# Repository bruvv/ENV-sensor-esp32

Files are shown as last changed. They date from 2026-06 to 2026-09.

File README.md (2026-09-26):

# ENV Sensor ESP32

Custom ESP32-S3 environmental sensor PCB designed for use with ESPHome and Home Assistant.

The board combines several environmental sensors, a 128×128 OLED display and an HLK-LD2450 mmWave presence sensor on a compact custom PCB.

## Features

- ESP32-S3 DevKitC N16R8
- Sensirion SCD30 CO₂ sensor
- Sensirion SEN55 environmental sensor
- MS5611 barometric pressure sensor
- BH1750 ambient light sensor
- ZJY-M150 128×128 OLED with SSD1327 controller
- HLK-LD2450 mmWave presence sensor
- Shared I²C bus for environmental sensors
- SPI interface for the OLED display
- Hardware UART for the LD2450
- 5 V and 3.3 V power rails
- 4-layer PCB
- 55 × 70 mm board
- Designed in KiCad 10

## Sensors

| Component | Function | Supply | Interface |
| --- | --- | ---: | --- |
| ESP32-S3 DevKitC N16R8 | Main controller, Wi-Fi and Bluetooth | 5 V | - |
| Sensirion SCD30 | CO₂, temperature and humidity | 5 V | I²C |
| Sensirion SEN55 | PM1.0, PM2.5, PM4, PM10, VOC, NOx, temperature and humidity | 5 V | I²C |
| MS5611 | Barometric pressure | 3.3 V | I²C |
| BH1750 | Ambient light | 3.3 V | I²C |
| ZJY-M150 / SSD1327 | 128×128 OLED display | 3.3 V | SPI |
| HLK-LD2450 | mmWave presence and multi-target tracking | 5 V | UART |

## ESP32 Pin Mapping

### I²C

| Signal | ESP32-S3 |
| --- | --- |
| SDA | GPIO8 |
| SCL | GPIO9 |

The environmental sensors share the I²C bus.

| Sensor | I²C address |
| --- | ---: |
| SCD30 | `0x61` |
| SEN55 | `0x69` |
| BH1750 | `0x23` |
| MS5611 | `0x77` |

The PCB contains 4.7 kΩ pull-up resistors for SDA and SCL.

## SSD1327 OLED

The ZJY-M150 OLED is operated in 4-wire SPI mode.

| OLED signal | ESP32-S3 |
| --- | --- |
| CS | GPIO10 |
| MOSI / SDA | GPIO11 |
| CLK / SCL | GPIO12 |
| DC | GPIO13 |
| RESET | GPIO14 |

## HLK-LD2450

The LD2450 uses a dedicated hardware UART.

| Signal | ESP32-S3 |
| --- | --- |
| LD2450 RX | GPIO17 / ESP32 TX |
| LD2450 TX | GPIO18 / ESP32 RX |

UART configuration:

- Baud rate: `256000`
- Data bits: `8`
- Parity: none
- Stop bits: `1`

## PCB

The current PCB revision is designed in KiCad 10.

| Property | Value |
| --- | --- |
| Dimensions | 55 × 70 mm |
| Copper layers | 4 |
| Top copper | `F.Cu` |
| Inner layer 1 | `In1.Cu` |
| Inner layer 2 | `In2.Cu` |
| Bottom copper | `B.Cu` |

The repository contains the KiCad project files as well as production Gerber and drill files.

## LD2450 Connector

The HLK-LD2450 is connected through an 8-pin dual-row SMD female socket.

Required connector specification:

| Property | Requirement |
| --- | --- |
| Type | Female PCB socket |
| Contacts | 8 |
| Rows | 2 × 4 |
| Pitch | 2.00 mm |
| Mounting | SMD / SMT |
| Orientation | Straight |

A suitable branded connector is:

**Würth Elektronik 62100821821**

- 2 × 4
- 8 contacts
- 2.00 mm pitch
- Female
- SMD

For generic alternatives, search for:

`2.0mm 2x4 8 pin female SMD header`

## SEN55 Connection

The SEN55 is mounted away from the main PCB to keep its airflow unobstructed.

The connection provides:

| Signal |
| --- |
| 5 V |
| GND |
| SDA |
| SCL |
| GND / SEL |

## Bill of Materials

| Qty | Component | Notes |
| ---: | --- | --- |
| 1 | ESP32-S3 DevKitC N16R8 | ESP32-S3-WROOM based |
| 1 | Sensirion SCD30 | CO₂ sensor |
| 1 | Sensirion SEN55 | Environmental and particulate sensor |
| 1 | MS5611 module | Pressure sensor |
| 1 | BH1750 module | Ambient light sensor |
| 1 | ZJY-M150 128×128 OLED | SSD1327 controller, 7-pin |
| 1 | HLK-LD2450 | mmWave presence sensor |
| 1 | 2×4 2.00 mm female SMD socket | LD2450 connector |
| 2 | 4.7 kΩ resistor | I²C pull-ups |

## Design Considerations

### SCD30

The SCD30 should be kept away from heat sources and strong direct airflow that could influence its temperature and CO₂ measurements.

Datasheet:  
https://sensirion.com/media/documents/4EAF6AF8/61652C3C/Sensirion_CO2_Sensors_SCD30_Datasheet.pdf

### SEN55

The SEN55 requires unobstructed airflow through its inlet and outlet.

For best performance:

- Keep the inlet and outlet separated.
- Avoid recirculating exhaust air into the inlet.
- Keep the sensor away from heat sources.
- Orient the sensor so dust cannot easily accumulate inside.
- Keep the fan inlet and exhaust unobstructed.

Datasheet:  
https://sensirion.com/media/documents/6791EFA0/62A1F68F/Sensirion_Datasheet_Environmental_Node_SEN5x.pdf

### MS5611

Keep the pressure sensor away from the ESP32 voltage regulator and other heat-producing components.

Datasheet:  
https://www.te.com/commerce/DocumentDelivery/DDEController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

### BH1750

The BH1750 needs a clear optical path to the room.

Avoid placing it behind opaque enclosure material or in the shadow of other components.

Datasheet:  
https://components101.com/sites/default/files/component_datasheet/BH1750.pdf

### SSD1327 OLED

The display is a ZJY-M150 1.5-inch 128×128 OLED using an SSD1327 controller.

The PCB uses SPI for the display.

SSD1327 datasheet:  
https://www.waveshare.com/w/upload/a/ac/SSD1327-datasheet.pdf

### HLK-LD2450

The LD2450 provides mmWave presence detection and multi-target position tracking.

Placement and enclosure design can significantly affect radar performance.

Recommendations:

- Face the radar toward the room.
- Avoid metal directly in front of the antenna.
- Keep sufficient clearance around the antenna area.
- Avoid placing large copper areas or metal parts directly in the radar field of view.

## Repository Structure

`envsensor/`  
KiCad schematic, PCB project and project-specific libraries.

`gerber/`  
Production Gerber and drill files.

`datasheet/`  
Component documentation.

`docs/`  
Hardware design and implementation documentation.

`README.md`  
Project documentation.

## Manufacturing

The `gerber/` directory contains the generated PCB production files, including:

- `F.Cu`
- `In1.Cu`
- `In2.Cu`
- `B.Cu`
- `F.Mask`
- `B.Mask`
- `F.Paste`
- `B.Paste`
- `F.Silkscreen`
- `B.Silkscreen`
- `Edge.Cuts`
- PTH drill file
- NPTH drill file

The repository also contains `gerber/gerber.zip`, which can be uploaded to most PCB manufacturers.

Always verify the Gerbers in the PCB manufacturer's Gerber viewer before placing an order.

## Software

The board is intended for use with ESPHome and Home Assistant.

Useful ESPHome documentation:

- SCD30: https://esphome.io/components/sensor/scd30/
- SEN5x: https://esphome.io/components/sensor/sen5x/
- BH1750: https://esphome.io/components/sensor/bh1750/
- MS5611: https://esphome.io/components/sensor/ms5611/
- SSD1327: https://esphome.io/components/display/ssd1327/
- LD2450: https://esphome.io/components/sensor/ld2450/

## License

See [LICENSE](LICENSE).

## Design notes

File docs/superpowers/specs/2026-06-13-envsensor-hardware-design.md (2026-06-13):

# ENV Sensor Hardware Design

## Scope

Finish and clean the KiCad schematic and PCB in `envsensor/`.

The board uses complete modules:

- ESP32-S3 DevKit from the existing project footprint
- Sensirion SCD30
- Sensirion SEN55, connected by cable
- MS5611 breakout
- Waveshare 1.5-inch SSD1327 128x128 OLED module
- BH1750 breakout
- HLK-LD2450 using the existing project footprint and onboard header

The PCB remains 52 x 70 mm. It has no mounting holes.

## Interfaces

### I2C

Use one shared 3.3 V I2C bus:

- SDA: ESP32-S3 GPIO8
- SCL: ESP32-S3 GPIO9
- SCD30: address 0x61
- SEN55: address 0x69
- BH1750: address 0x23
- MS5611: address 0x77

Add one pair of 4.7 kOhm pull-up resistors to 3.3 V. Keep the bus suitable
for the external SEN55 cable. Connect SEN55 SEL to GND to select I2C.

### Display

Use the SSD1327 in its factory-default four-wire SPI mode:

- MOSI: GPIO11
- CLK: GPIO12
- CS: GPIO10
- DC: GPIO13
- RESET: GPIO14

The display is powered from 3.3 V.

### Radar

Use a hardware UART for the LD2450:

- ESP32 TX: GPIO17 to LD2450 RX
- ESP32 RX: GPIO18 from LD2450 TX
- 256000 baud, no parity, one stop bit

Preserve the existing LD2450 footprint as the mechanical basis.

## Power

Power the assembly through the ESP32-S3 DevKit USB connector.

- 5VIN powers SCD30, SEN55, and LD2450.
- 3V3 powers SSD1327, BH1750, MS5611, and I2C pull-ups.
- Add local bulk and decoupling capacitance on both rails.
- Use wider 5 V tracks for the fan-based SEN55 and other 5 V modules.

Do not use ESP32-S3 strapping pins, native USB pins, or flash/PSRAM pins
for these interfaces.

## Connectors And Assembly

- SCD30, MS5611, BH1750, SSD1327, and ESP32-S3 are soldered to the board.
- SEN55 sits away from the PCB and connects through a JST GHR-06V-S
  six-pin cable connector.
- LD2450 plugs directly into the existing onboard header arrangement.
- Place clear silkscreen labels for module names, connector pinout, pin 1,
  power rails, and orientation.

## Mechanical Layout

Use layout option A.

Front:

- SSD1327 at the top.
- BH1750 below the display with an unobstructed light path.
- LD2450 at the bottom, facing into the room.

Back:

- ESP32-S3 on the left, with USB accessible at the bottom edge.
- SCD30 on the right with unobstructed airflow openings.
- MS5611 below the SCD30 and away from heat sources.
- SEN55 connector at the bottom edge.

Keep SCD30 and MS5611 away from the ESP32 regulator and other heat sources.
Respect antenna and copper keep-out requirements for the ESP32-S3 and
LD2450.

## Schematic Structure

Organize the schematic into readable blocks:

1. Power and decoupling
2. ESP32-S3
3. I2C sensors
4. SSD1327 display
5. LD2450 radar

Use these references:

- U1: ESP32-S3
- U2: SCD30
- U3: MS5611
- U4: BH1750
- U5: SSD1327
- J1: SEN55
- U6: LD2450

Mark intentionally unused module pins as no-connect.

## PCB Routing

- Use two copper layers with GND pours.
- Keep I2C tracks short, grouped, and away from noisy power routing.
- Keep SPI routing short between ESP32-S3 and SSD1327.
- Route UART separately from sensor lines.
- Provide clean return paths and stitching vias where useful.
- Preserve the 52 x 70 mm rectangular board outline.

## Validation

- Run KiCad ERC on the finished schematic.
- Run KiCad DRC on the fully placed and routed PCB.
- Resolve all actionable findings.
- Document any accepted warning with a concrete hardware reason.
- Confirm footprints, connector orientation, module clearances, power
  rails, and pin mappings against manufacturer documentation.

ESPHome configuration is outside this task.

## Sources

- ESPHome SSD1327:
  https://esphome.io/components/display/ssd1327/
- ESPHome I2C:
  https://esphome.io/components/i2c/
- ESPHome SCD30:
  https://esphome.io/components/sensor/scd30/
- ESPHome SEN5x:
  https://esphome.io/components/sensor/sen5x/
- ESPHome BH1750:
  https://esphome.io/components/sensor/bh1750/
- ESPHome MS5611:
  https://esphome.io/components/sensor/ms5611/
- ESPHome LD2450:
  https://esphome.io/components/sensor/ld2450/
- Waveshare SSD1327 module:
  https://www.waveshare.com/wiki/1.5inch_OLED_Module
- Sensirion SEN5x datasheet:
  https://sensirion.com/media/documents/6791EFA0/62A1F68F/Sensirion_Datasheet_Environmental_Node_SEN5x.pdf
- Espressif ESP32-S3 GPIO restrictions:
  https://docs.espressif.com/projects/esp-idf/en/stable/esp32s3/api-reference/peripherals/gpio.html

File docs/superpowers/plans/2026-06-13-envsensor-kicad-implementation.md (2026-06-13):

# ENV Sensor KiCad Implementation Plan

> **For agentic workers:** REQUIRED SUB-SKILL: Use superpowers:subagent-driven-development (recommended) or superpowers:executing-plans to implement this plan task-by-task. Steps use checkbox (`- [ ]`) syntax for tracking.

**Goal:** Deliver a clean KiCad 10 schematic and fully placed, routed, two-layer 52 x 70 mm PCB for the ESPHome environmental sensor.

**Architecture:** Restore the useful KiCad recovery files into the active project, then rebuild connectivity around one 3.3 V I2C bus, one SSD1327 SPI bus, and one LD2450 hardware UART. Reuse the existing module footprints where they match the hardware, add only the missing display and SEN55 connector definitions, and validate the result with KiCad ERC, DRC, schematic parity, and visual exports.

**Tech Stack:** KiCad 10.0.3, `kicad-cli`, KiCad schematic editor, KiCad PCB editor, two-layer PCB.

---

## File Map

- Modify: `envsensor/envsensor.kicad_sch` - complete schematic and net definitions.
- Create: `envsensor/envsensor.kicad_pcb` - active routed PCB restored from the best recovery board.
- Modify: `envsensor/envsensor.kicad_pro` - project rules and library references where required.
- Modify: `envsensor/sym-lib-table` - project-local symbol library registration.
- Modify: `envsensor/fp-lib-table` - project-local footprint library registration.
- Create: `envsensor/lib/envsensor.kicad_sym` - missing module symbols only.
- Create: `envsensor/lib/envsensor.pretty/SSD1327_Waveshare_1.5in.kicad_mod` - display module footprint and mechanical outline.
- Create: `envsensor/reports/erc.json` - final ERC report.
- Create: `envsensor/reports/drc.json` - final DRC and schematic parity report.
- Create: `envsensor/reports/front.png` - top-side 3D visual review export.
- Create: `envsensor/reports/back.png` - bottom-side 3D visual review export.

## Fixed Net Map

| Net | ESP32-S3 pin | Destinations |
| --- | --- | --- |
| `I2C_SDA` | GPIO8 | SCD30 SDA, SEN55 SDA, MS5611 SDA, BH1750 SDA |
| `I2C_SCL` | GPIO9 | SCD30 SCL, SEN55 SCL, MS5611 SCL, BH1750 SCL |
| `OLED_CS` | GPIO10 | SSD1327 CS |
| `OLED_MOSI` | GPIO11 | SSD1327 DIN |
| `OLED_CLK` | GPIO12 | SSD1327 CLK |
| `OLED_DC` | GPIO13 | SSD1327 DC |
| `OLED_RST` | GPIO14 | SSD1327 RST |
| `RADAR_TX` | GPIO17 | LD2450 RX |
| `RADAR_RX` | GPIO18 | LD2450 TX |
| `+5V` | 5VIN | SCD30 VDD, SEN55 VDD, LD2450 5V |
| `+3V3` | 3V3 | SSD1327 VCC, MS5611 VCC, BH1750 VCC, I2C pull-ups |
| `GND` | GND | All modules and decoupling |

### Task 1: Restore Active KiCad Board

**Files:**
- Replace: `envsensor/envsensor.kicad_sch`
- Create: `envsensor/envsensor.kicad_pcb`

- [ ] **Step 1: Preserve the active schematic outside the implementation diff**

Copy `envsensor/envsensor.kicad_sch` to a temporary file under `/tmp`; do not add another repository backup.

Run:

```bash
cp envsensor/envsensor.kicad_sch /tmp/envsensor-before-restore.kicad_sch
```

Expected: `/tmp/envsensor-before-restore.kicad_sch` exists.

- [ ] **Step 2: Restore the richer schematic and PCB**

Use:

```text
envsensor/_restore_backup_2026-05-30T16-42-54-646/envsensor.kicad_sch
envsensor/_restore_backup_2026-05-30T16-42-54-646/envsensor.kicad_pcb
```

Copy them to:

```text
envsensor/envsensor.kicad_sch
envsensor/envsensor.kicad_pcb
```

Expected: active schematic contains ESP32-S3, LD2450, SCD30, MS5611, and BH1750; active board has a 52 x 70 mm `Edge.Cuts` rectangle.

- [ ] **Step 3: Verify both files parse in KiCad 10**

Run:

```bash
/Applications/KiCad/KiCad.app/Contents/MacOS/kicad-cli sch export netlist \
  --output /tmp/envsensor-restored.net \
  envsensor/envsensor.kicad_sch

/Applications/KiCad/KiCad.app/Contents/MacOS/kicad-cli pcb render \
  --output /tmp/envsensor-restored.png \
  envsensor/envsensor.kicad_pcb
```

Expected: both commands exit 0.

- [ ] **Step 4: Commit only active recovery**

```bash
git add envsensor/envsensor.kicad_sch envsensor/envsensor.kicad_pcb
git commit -m "chore(kicad): restore active design"
```

### Task 2: Add Missing Local Library Definitions

**Files:**
- Create: `envsensor/lib/envsensor.kicad_sym`
- Create: `envsensor/lib/envsensor.pretty/SSD1327_Waveshare_1.5in.kicad_mod`
- Modify: `envsensor/sym-lib-table`
- Modify: `envsensor/fp-lib-table`

- [ ] **Step 1: Register one project-local library**

Add:

```scheme
(lib (name "envsensor")(type "KiCad")(uri "${KIPRJMOD}/lib/envsensor.kicad_sym")(options "")(descr "ENV sensor project symbols"))
```

to `envsensor/sym-lib-table`, and:

```scheme
(lib (name "envsensor")(type "KiCad")(uri "${KIPRJMOD}/lib/envsensor.pretty")(options "")(descr "ENV sensor project footprints"))
```

to `envsensor/fp-lib-table`.

- [ ] **Step 2: Create SSD1327 module symbol**

Create symbol `SSD1327_Waveshare_1.5in` with these pins:

| Number | Name | Type |
| --- | --- | --- |
| 1 | VCC | power input |
| 2 | GND | power input |
| 3 | DIN | input |
| 4 | CLK | input |
| 5 | CS | input |
| 6 | DC | input |
| 7 | RST | input |

Assign footprint:

```text
envsensor:SSD1327_Waveshare_1.5in
```

- [ ] **Step 3: Create SSD1327 footprint**

Use the official Waveshare 2D drawing from:

```text
https://files.waveshare.com/wiki/1.5inch%20OLED%20Module/1_5inch_oled_module_size.pdf
```

The footprint must contain:

- Seven plated through holes matching the module header.
- Pin 1 marker.
- 44.5 x 37 mm module body on `F.Fab`.
- Display/body outline on `F.SilkS` without crossing pads.
- Courtyard enclosing the full module.
- Clear connector-side and display-side labels.

- [ ] **Step 4: Use standard SEN55 board connector**

Use symbol `Connector_Generic:Conn_01x06` and footprint:

```text
Connector_JST:JST_GH_SM06B-GHS-TB_1x06-1MP_P1.25mm_Horizontal
```

Pin names in schematic:

| Pin | Net |
| --- | --- |
| 1 | `+5V` |
| 2 | `GND` |
| 3 | `I2C_SDA` |
| 4 | `I2C_SCL` |
| 5 | `GND` (`SEL`) |
| 6 | no-connect |

- [ ] **Step 5: Validate library loading**

Open the project in KiCad 10 and confirm both `envsensor` libraries load without rescue or missing-library dialogs.

- [ ] **Step 6: Commit library definitions**

```bash
git add envsensor/lib/envsensor.kicad_sym \
  envsensor/lib/envsensor.pretty/SSD1327_Waveshare_1.5in.kicad_mod \
  envsensor/sym-lib-table envsensor/fp-lib-table
git commit -m "feat(kicad): add display and sensor connector"
```

### Task 3: Rebuild And Clean Schematic

**Files:**
- Modify: `envsensor/envsensor.kicad_sch`

- [ ] **Step 1: Normalize references and values**

Set:

```text
U1 ESP32-S3 DevKit
U2 SCD30
U3 MS5611
U4 BH1750
U5 SSD1327
J1 SEN55
U6 LD2450
R1 4.7k I2C SDA pull-up
R2 4.7k I2C SCL pull-up
C1 10u +5V bulk
C2 100n +5V decoupling
C3 10u +3V3 bulk
C4 100n +3V3 decoupling
```

- [ ] **Step 2: Arrange schematic blocks**

Place five readable blocks from left to right:

```text
Power -> ESP32-S3 -> I2C sensors -> SSD1327 SPI -> LD2450 UART
```

Use global power symbols and named net labels instead of long crossing wires.

- [ ] **Step 3: Wire power**

Connect:

```text
ESP32 5VIN -> +5V
ESP32 3V3 -> +3V3
all module grounds -> GND
C1/C2 between +5V and GND
C3/C4 between +3V3 and GND
```

Add power flags only where ERC needs proof that the DevKit rails are driven.

- [ ] **Step 4: Wire the I2C bus**

Connect `I2C_SDA` and `I2C_SCL` according to the fixed net map.

Configure module mode pins:

```text
BH1750 ADDR -> GND for address 0x23
MS5611 PS -> +3V3 for I2C
MS5611 CSB -> +3V3 for address 0x77
MS5611 SDO -> no-connect
SCD30 SEL -> GND for I2C
SCD30 RDY and PWM -> no-connect
J1 pin 5 SEL -> GND
J1 pin 6 -> no-connect
```

Connect `R1` from `I2C_SDA` to `+3V3` and `R2` from `I2C_SCL` to `+3V3`.

- [ ] **Step 5: Wire display and radar**

Connect the SSD1327 and LD2450 exactly according to the fixed net map. Mark all unused LD2450 pads and unused ESP32-S3 GPIO pins as no-connect.

- [ ] **Step 6: Annotate and assign footprints**

Run annotation with existing references reset, then verify the final references match the approved reference list. Assign the restored project footprints for ESP32-S3, SCD30, MS5611, BH1750, and LD2450.

- [ ] **Step 7: Commit schematic**

```bash
git add envsensor/envsensor.kicad_sch envsensor/envsensor.kicad_pro
git commit -m "feat(kicad): complete sensor schematic"
```

### Task 4: Make ERC Clean

**Files:**
- Modify: `envsensor/envsensor.kicad_sch`
- Create: `envsensor/reports/erc.json`

- [ ] **Step 1: Run ERC**

```bash
mkdir -p envsensor/reports
/Applications/KiCad/KiCad.app/Contents/MacOS/kicad-cli sch erc \
  --format json \
  --severity-all \
  --exit-code-violations \
  --output envsensor/reports/erc.json \
  envsensor/envsensor.kicad_sch
```

Expected initially: possible power-driver or unconnected-pin violations.

- [ ] **Step 2: Resolve actionable findings**

Fix incorrect pin types, missing power flags, missing no-connect markers, duplicate references, and missing footprints. Do not suppress a warning merely to make the report empty.

- [ ] **Step 3: Re-run ERC**

Run the same command.

Expected: exit 0 with no error or warning violations.

- [ ] **Step 4: Commit ERC-clean schematic**

```bash
git add envsensor/envsensor.kicad_sch envsensor/reports/erc.json
git commit -m "fix(kicad): resolve schematic checks"
```

### Task 5: Place Components In Layout A

**Files:**
- Modify: `envsensor/envsensor.kicad_pcb`

- [ ] **Step 1: Update PCB from schematic**

Import all schematic changes into the restored PCB. Remove obsolete footprints only when they are absent from the approved schematic.

- [ ] **Step 2: Preserve board outline**

Verify `Edge.Cuts` remains one closed rectangle:

```text
52 mm wide
70 mm high
no mounting holes
```

- [ ] **Step 3: Place front-side modules**

Place:

```text
SSD1327 at top
BH1750 below display with clear light path
LD2450 at bottom with radar face toward bottom board edge/room
```

Keep the LD2450 existing header and module geometry. Add copper keep-out under its antenna/radar-sensitive area where required by the module footprint.

- [ ] **Step 4: Place back-side modules**

Place:

```text
ESP32-S3 on left, USB at bottom edge
SCD30 on right, airflow openings unobstructed
MS5611 below SCD30 and away from regulator
J1 SEN55 at bottom edge, cable exiting downward
```

Place pull-ups and decoupling close to their rails and loads.

- [ ] **Step 5: Verify mechanical clearances**

Check front/back body overlap in 3D viewer, not only courtyard overlap. Confirm USB, SEN55 cable, SCD30 airflow, OLED face, BH1750 light path, ESP32 antenna, and LD2450 field of view remain accessible.

- [ ] **Step 6: Commit placement**

```bash
git add envsensor/envsensor.kicad_pcb
git commit -m "feat(kicad): place env sensor modules"
```

### Task 6: Route Power, Signals, And Planes

**Files:**
- Modify: `envsensor/envsensor.kicad_pcb`

- [ ] **Step 1: Configure net classes**

Use:

```text
Default signals: 0.25 mm track, 0.20 mm clearance
+3V3: 0.50 mm track
+5V: 0.80 mm track
```

Use larger widths where a connector or module pad permits.

- [ ] **Step 2: Route high-current power first**

Route USB-derived `+5V` from ESP32 5VIN to SCD30, J1 SEN55, and LD2450. Keep return paths short and avoid routing the fan current through sensor ground stubs.

- [ ] **Step 3: Route buses**

Route:

```text
I2C_SDA and I2C_SCL together without unnecessary vias
OLED SPI as short direct tracks
RADAR_TX and RADAR_RX away from I2C and power switching loops
```

- [ ] **Step 4: Add GND zones**

Add `GND` copper zones on `F.Cu` and `B.Cu`, respecting ESP32 and LD2450 keep-outs. Add stitching vias where they improve return continuity and do not obstruct modules.

- [ ] **Step 5: Finish silkscreen**

Add readable labels:

```text
ENV SENSOR
ESP32-S3
SCD30
SEN55
MS5611
BH1750
SSD1327
LD2450
J1: 5V GND SDA SCL SEL NC
```

Keep all silkscreen clear of pads and board edge.

- [ ] **Step 6: Commit routing**

```bash
git add envsensor/envsensor.kicad_pcb envsensor/envsensor.kicad_pro
git commit -m "feat(kicad): route env sensor board"
```

### Task 7: Make DRC And Schematic Parity Clean

**Files:**
- Modify: `envsensor/envsensor.kicad_pcb`
- Create: `envsensor/reports/drc.json`

- [ ] **Step 1: Refill zones and run DRC**

```bash
/Applications/KiCad/KiCad.app/Contents/MacOS/kicad-cli pcb drc \
  --format json \
  --severity-all \
  --schematic-parity \
  --refill-zones \
  --save-board \
  --exit-code-violations \
  --output envsensor/reports/drc.json \
  envsensor/envsensor.kicad_pcb
```

Expected initially: possible courtyard, silkscreen, unconnected-item, or clearance findings.

- [ ] **Step 2: Resolve actionable findings**

Fix every unconnected net, clearance issue, invalid courtyard overlap, silkscreen-pad collision, malformed keep-out, and schematic/PCB mismatch.

- [ ] **Step 3: Re-run DRC**

Run the same command.

Expected: exit 0 with zero error or warning violations and zero unconnected items.

- [ ] **Step 4: Commit DRC-clean PCB**

```bash
git add envsensor/envsensor.kicad_pcb envsensor/reports/drc.json
git commit -m "fix(kicad): resolve board checks"
```

### Task 8: Export And Visually Verify

**Files:**
- Create: `envsensor/reports/front.png`
- Create: `envsensor/reports/back.png`

- [ ] **Step 1: Export front and back review images**

```bash
/Applications/KiCad/KiCad.app/Contents/MacOS/kicad-cli pcb render \
  --side top \
  --quality high \
  --output envsensor/reports/front.png \
  envsensor/envsensor.kicad_pcb

/Applications/KiCad/KiCad.app/Contents/MacOS/kicad-cli pcb render \
  --side bottom \
  --quality high \
  --output envsensor/reports/back.png \
  envsensor/envsensor.kicad_pcb
```

- [ ] **Step 2: Inspect both sides**

Verify:

- Module orientations match silkscreen.
- No module extends beyond the board except intended USB/cable access.
- SCD30 air openings and BH1750 optical path are clear.
- ESP32 and LD2450 keep-outs contain no copper.
- Connector pin 1 and SEN55 pin labels are unambiguous.
- Power and signal tracks do not have accidental neck-downs.

- [ ] **Step 3: Run final checks**

```bash
/Applications/KiCad/KiCad.app/Contents/MacOS/kicad-cli sch erc \
  --format json --severity-all --exit-code-violations \
  --output envsensor/reports/erc.json \
  envsensor/envsensor.kicad_sch

/Applications/KiCad/KiCad.app/Contents/MacOS/kicad-cli pcb drc \
  --format json --severity-all --schematic-parity \
  --refill-zones --save-board --exit-code-violations \
  --output envsensor/reports/drc.json \
  envsensor/envsensor.kicad_pcb
```

Expected: both commands exit 0.

- [ ] **Step 4: Commit final review artifacts**

```bash
git add envsensor/reports envsensor/envsensor.kicad_sch \
  envsensor/envsensor.kicad_pcb envsensor/envsensor.kicad_pro
git commit -m "test(kicad): add final design checks"
```

## Final Acceptance

- Active schematic and PCB open without missing libraries.
- References and values match the approved design.
- Board outline is exactly 52 x 70 mm.
- No mounting holes are present.
- SSD1327 uses SPI; sensors use I2C; LD2450 uses hardware UART.
- USB-derived rails power all modules correctly.
- SEN55 uses the six-pin JST GH cable connector and sits off-board.
- Layout A is implemented.
- ERC and DRC with schematic parity pass.
- Front and back renders show no mechanical or orientation defect.

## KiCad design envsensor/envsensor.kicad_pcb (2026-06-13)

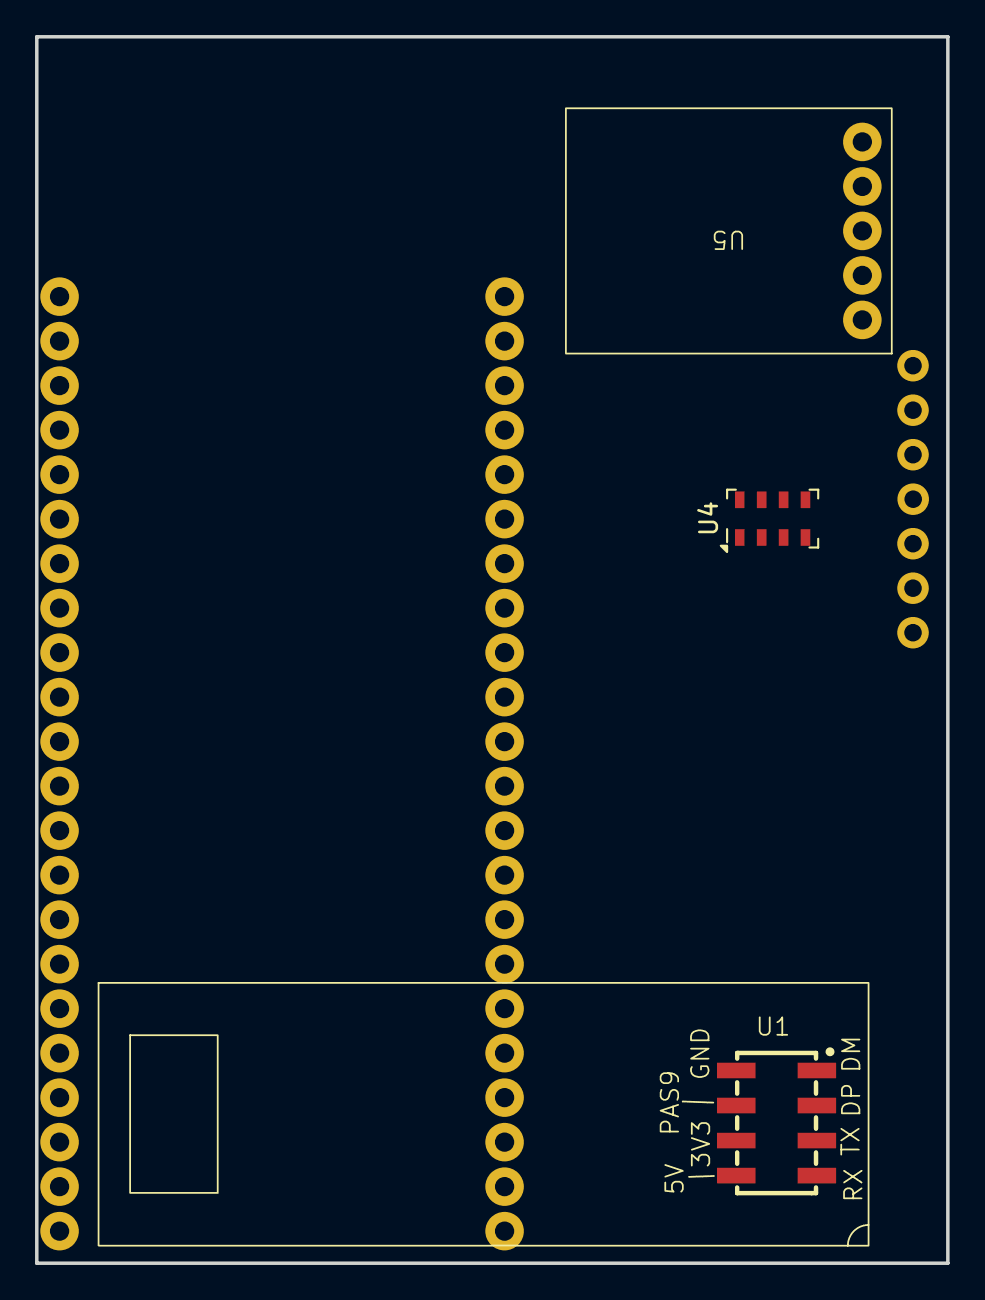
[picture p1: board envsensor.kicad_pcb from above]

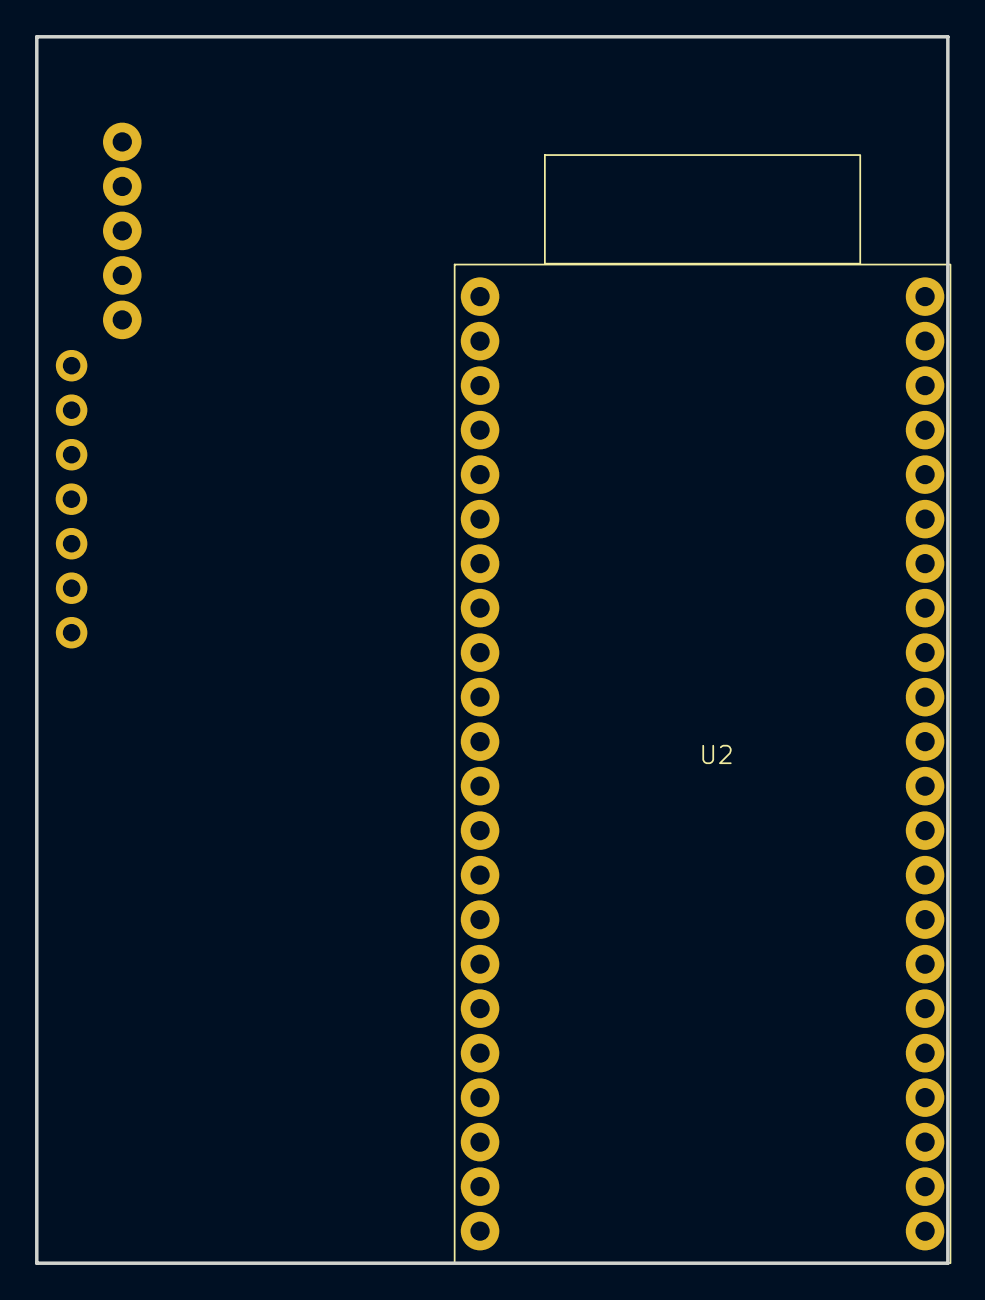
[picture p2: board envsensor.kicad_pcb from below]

Board: 2 copper layers, 52.0 x 70.0 mm, 5 parts (2 on the bottom side), 3 nets, no tracks yet.

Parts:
U1: LD2450; ld2450
U2: esp32-s3-wroom-1-devkit
U3: SCD30
U4: MS5611-01BA; LGA-8_3x5mm_P1.25mm
U5: BH1750

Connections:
3V3: U1.6 (3V3), U3.1 (VDD)
GND: U1.8 (GND), U3.2 (GND), U4.3 (GND)
unnamed: U4.4 (CSB), U4.5 (CSB)

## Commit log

2026-01-04 Expand README with sensor considerations and guidelines
    Added considerations and guidelines for various sensors including SCD30, SEN55, and LD2450.
2026-06-13 Add new components and libraries for environmental sensor project
    - Created schematic for ESP32 WROOM 1 Devkit in envsensor.kicad_sch.
    - Added footprint library entry for LD2450 in fp-lib-table.
    - Established backup and main symbol files for BH1750 light sensor in bh1750.bak and bh1750.kicad_sym.
    - Defined module for BH1750 in BH1750-MODULE.kicad_mod with appropriate pads and silk screen markings.
    - Updated sym-lib-table to include LD2450 symbol library.
    [envsensor.kicad_pcb, envsensor.kicad_sch]
2026-06-13 docs: add env sensor hardware design
2026-06-13 docs: add KiCad implementation plan
2026-06-13 added led screen
    [envsensor.kicad_pcb, envsensor.kicad_sch]
2026-06-15 final version
    [envsensor-B_Cu.gbr, envsensor-B_Mask.gbr, envsensor-B_Paste.gbr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]
2026-09-26 Revise README for ENV Sensor ESP32 details
    Updated the README to enhance clarity and detail about the ENV Sensor ESP32, including sensor specifications, features, and design considerations.
